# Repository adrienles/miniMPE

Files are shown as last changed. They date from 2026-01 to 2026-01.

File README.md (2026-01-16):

# miniMPE
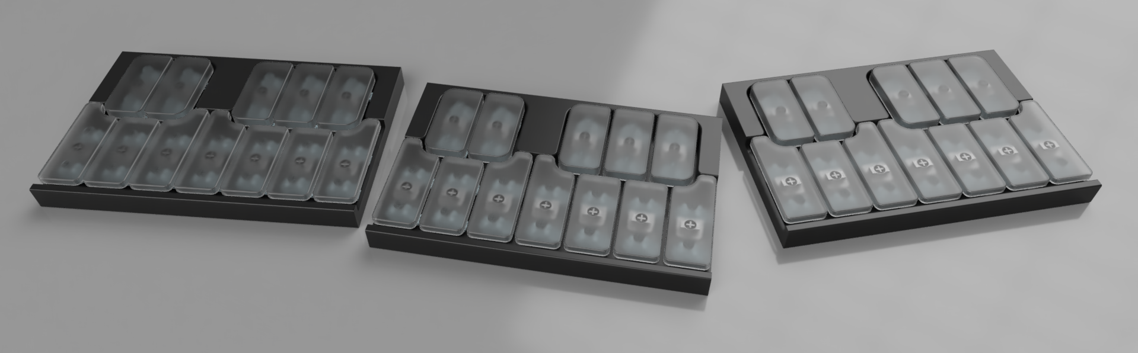
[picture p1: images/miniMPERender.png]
Early prototype render of miniMPE

An ultra-compact expressive octave-sectioned MIDI keyboard
## Idea

Originally inspired by the KORG nanoKeys line of ultra-compact MIDI keyboards, I wanted to design an alternative, with a few improvements:

- Standard key width
- Velocity sensitivity
    - The nanoKeys is not velocity sensitive, as it uses rubber-dome-like keys.
- RGB lighting for scale highlighting and pretty effects
- Daisy-chainable design, to go beyond a 2 octave design
    - This will likely be done using magnetic pogo pin connectors, for an easy and durable connection.
- Open Source :)
## Sub-projects
### MCU Test Board
This is a 4-layer test PCB designed to test one of the chosen MCU picks, alongside its dual USB peripherals, which this project might utilize.
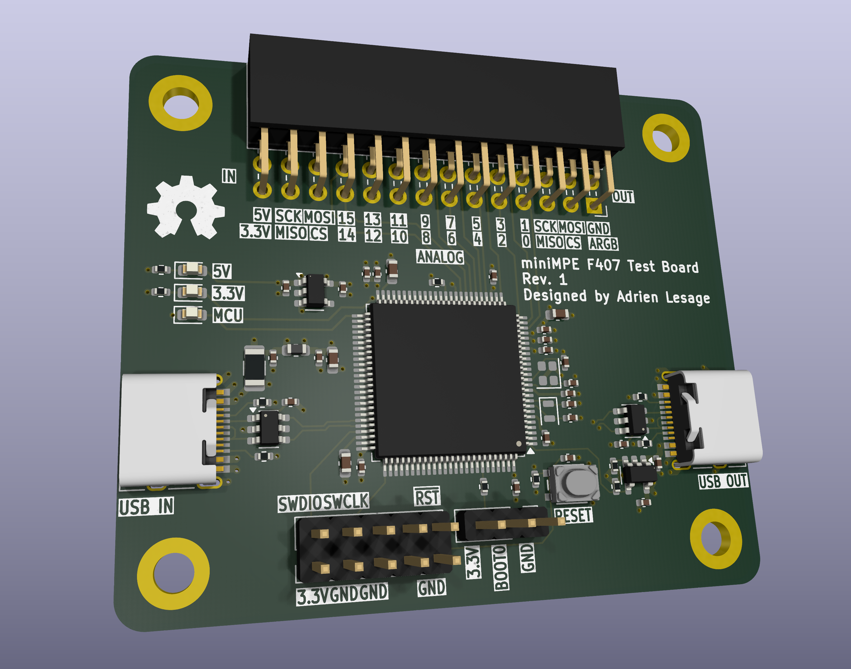
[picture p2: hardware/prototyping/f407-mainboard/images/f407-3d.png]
3D render of F407 PCB

#### Specs
- STM32F407 MCU
    - Dual USB peripherals
- IO header with dual SPI and 16 analog channels
- Dual USB ports
    - Output is protected against over-voltage
- Impedance matched USB and digital signals
- 4-layer design (Signal - Power/Gnd - Gnd - Signal)
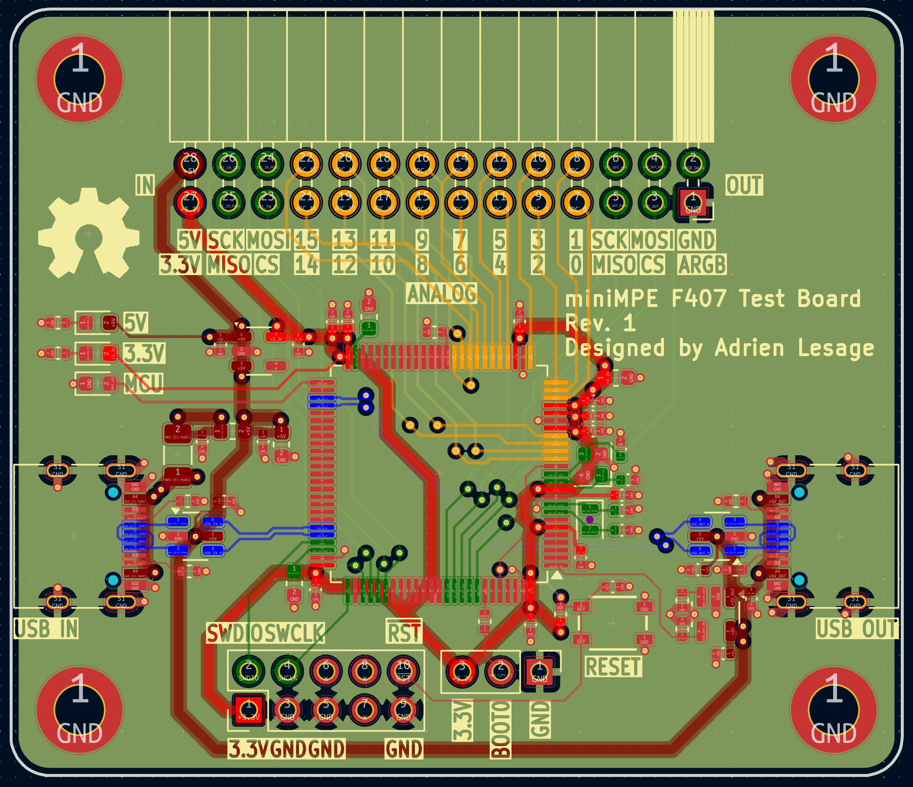
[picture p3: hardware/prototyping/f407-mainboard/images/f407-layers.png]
Layer view of F407 PCB


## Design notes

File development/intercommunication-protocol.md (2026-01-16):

# intercommunication protocol ideas
## options
### usb
#### pros
- naturally, a usb-c connector could be used
- sections could be used and connected to a host device independently, which is a neat feature
#### cons
- to respect the spec (which should be done), only 5v could be passed, requiring each section to regulate its own power instead of simply the host section
- thick protocol layer that is kinda useless in this scenario, could add latency
### i3c
#### pros (especially over i2c)
- hot-join support!
- dynamic addresses (important!)
#### cons
- veeeeery few mcu support it, so it's a no go
### uart
#### pros
- very simple
- could just fifo into the previous section, until the host section
- a very basic mcu could be used
#### cons
- janky i guess?
## choice
- i really like the appeal of each half working on its own, so usb is a natural first choice
  - more extensive testing is needed. if usb does the trick, i'll probably go forward with it

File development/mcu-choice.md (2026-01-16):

# mcu choice
## picks
### stm32f407
#### pros
- powerful
- 2 usb phys
- st, so good software support/docs
#### cons
- expensive
  - ~$2.70/u
- power consumption
  - ~87 mA at max freq + peripherals
    - too much for final product if daisy chaining a bunch (say 5 sections + 1 host for 61 keys, 6*87 = 522 mA, which might be pushing it for bus/battery power)
### ch32v203
#### pros
- decent power
- 2 usb phys
- cheap*
  - c8 @ ~$0.84/u
    - this variant only has 10 adc channels, which would require an extra analog mux
  - rb @ ~$1.69/u
    - this variant has 16 adc channels, which is just enough. however, the cost difference is large enough where the extra mux might be worth it
- low power
  - ~11.8 mA at max freq + peripherals
#### cons
- far from the best support/docs...
- cheap variant has few adc pins

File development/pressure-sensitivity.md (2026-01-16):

# pressure sensitivity
## general idea
- pcb button pad with velostat or other pressure-resistive sheet material
## criteria
- repeatability
- pressure/resistance
- reliability/noise
## ressources
TODO
## iterating
TODO

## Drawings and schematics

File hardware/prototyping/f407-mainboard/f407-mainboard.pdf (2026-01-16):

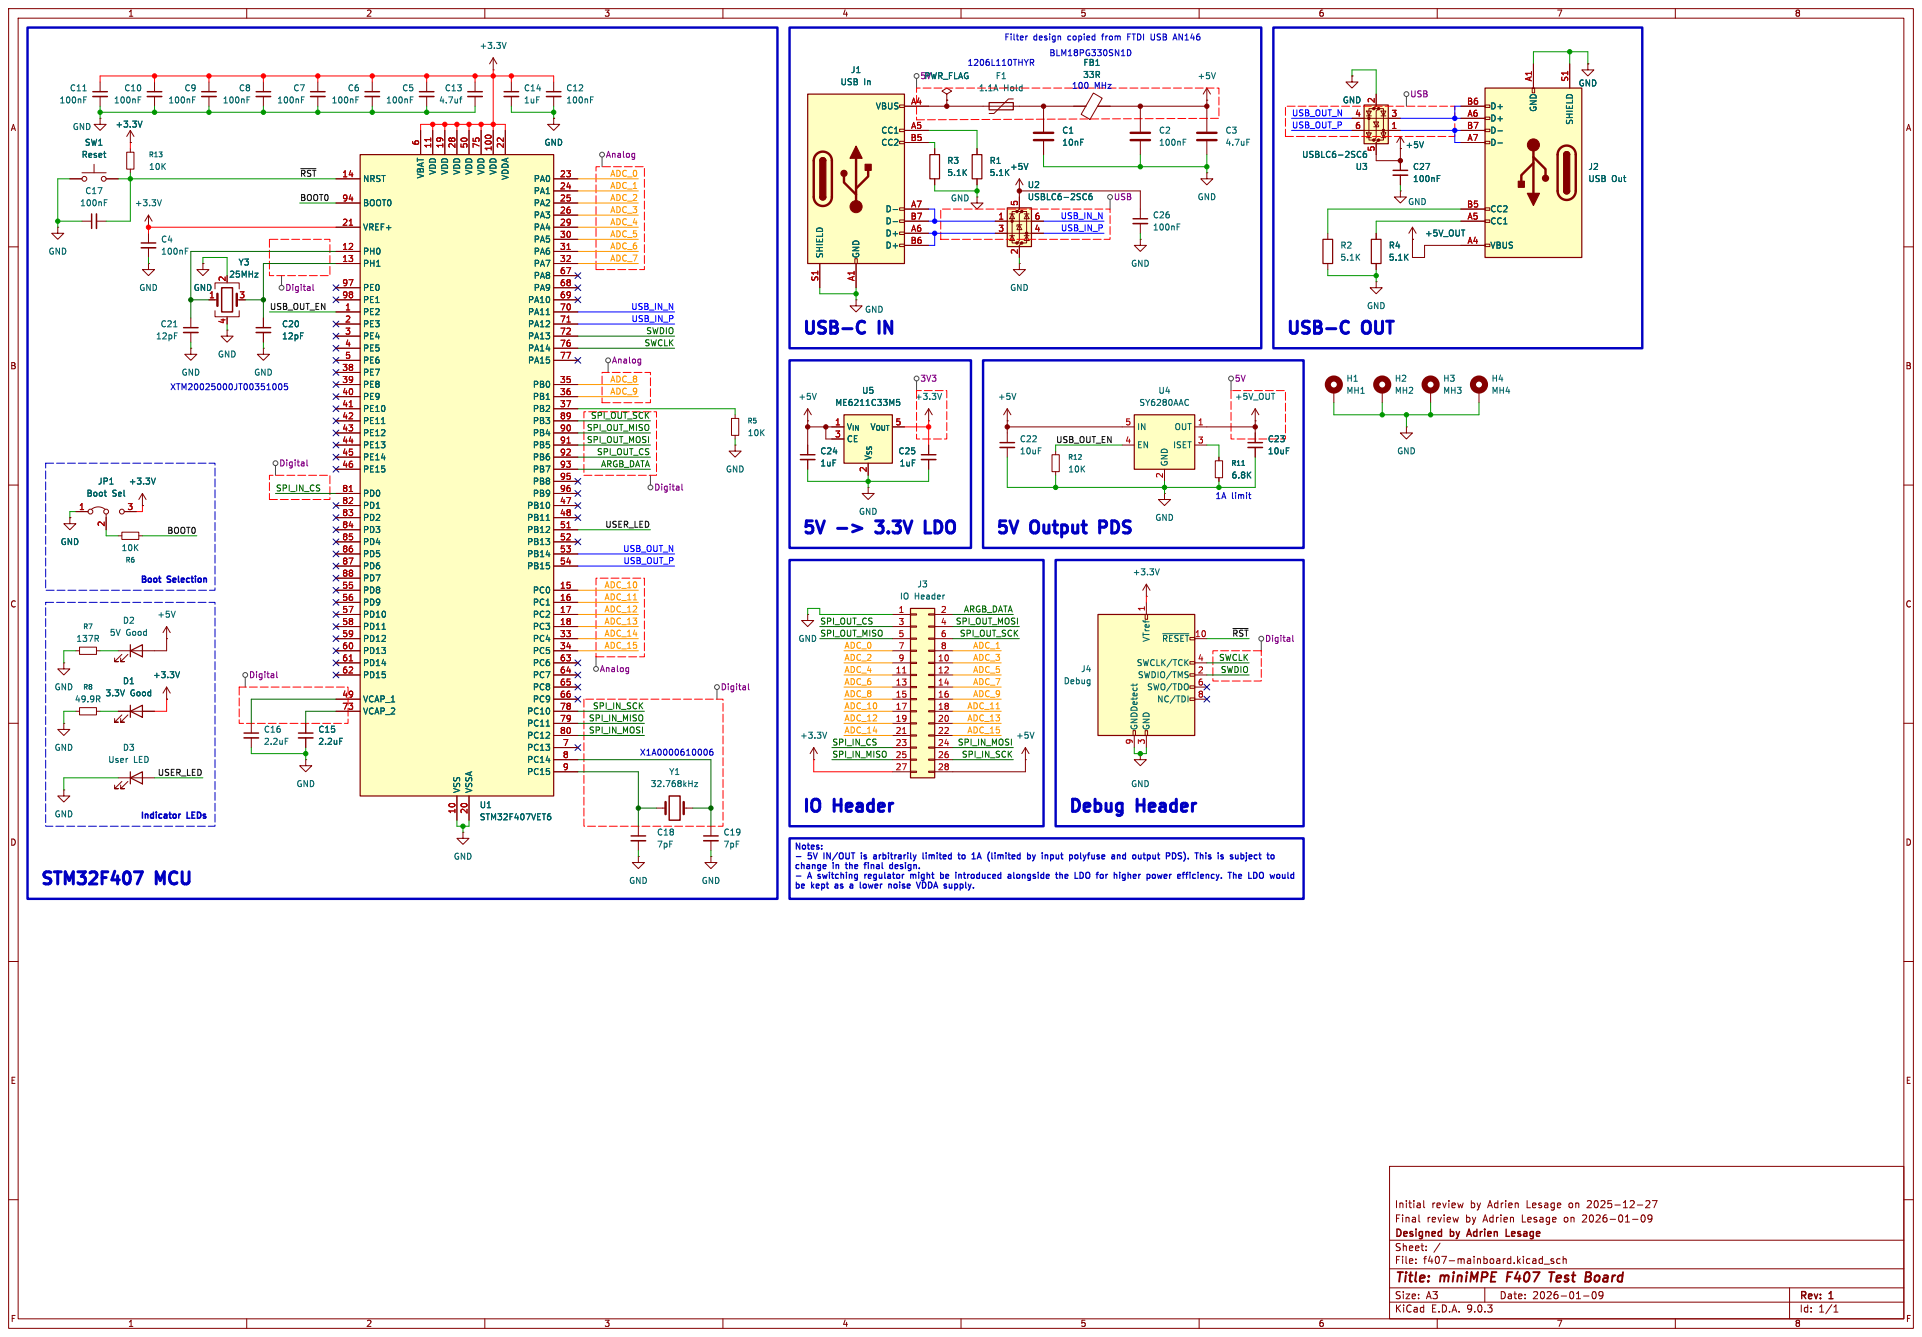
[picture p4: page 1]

6 VDD 11 VDD 19 VDD 28 VSS 10 VDD 50 VSSA 20 VDD 75 VDD 100 VDDA 22 PA0 23 PA1 24 PA2 25 PA3 26 PA4 29 PA5 30 PA6 31 PA7 32 PA8 67 PA9 68 PA10 69 PA11 70 PA12 71 PA13 72 PA14 76 PA15 77 PB0 35 PB1 36 PB2 37 PB3 89 PB4 90 PB5 91 PB6 92 PB7 93 PB8 95 PB9 96 PB10 47 PB11 48 PB12 51 PB13 52 PB14 53 PB15 54 PC0 15 PC1 16 PC2 17 PC3 18 PC4 33 PC5 34 PC6 63 PC7 64 PC8 65 PC9 66 PC10 78 PC11 79 PC12 80 PC13 7 PC14 8 PC15 9 U1STM32F407VET6

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

3 ~{RESET}10 SWCLK/TCK 4 SWDIO/TMS 2 SWO/TDO 6 NC/TDI 8

be kept as a lower noise VDDA supply.

Id: 1/1 Title: miniMPE F407 Test Board

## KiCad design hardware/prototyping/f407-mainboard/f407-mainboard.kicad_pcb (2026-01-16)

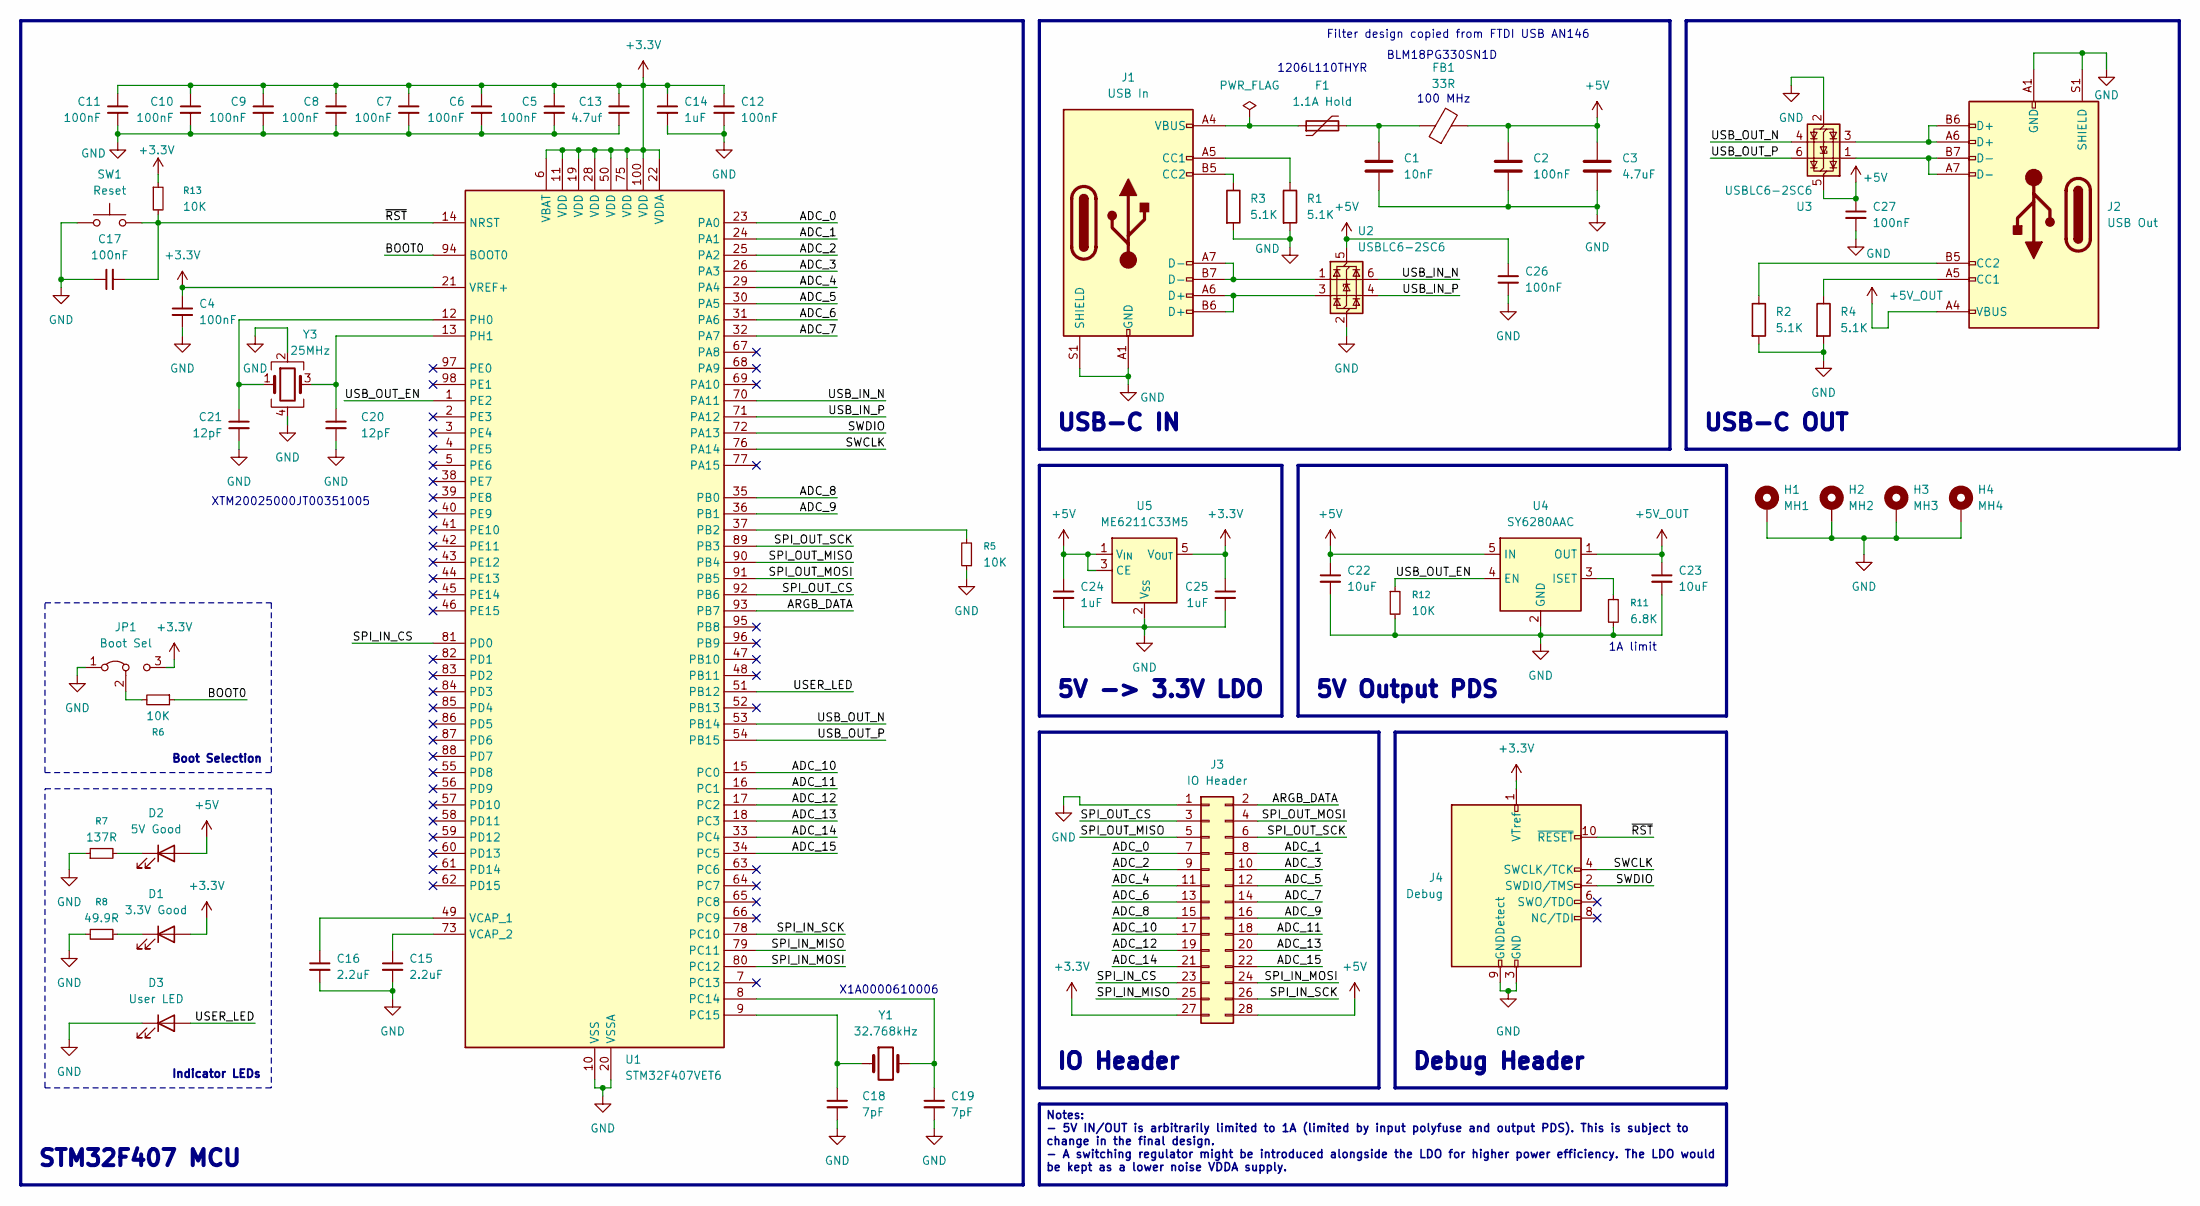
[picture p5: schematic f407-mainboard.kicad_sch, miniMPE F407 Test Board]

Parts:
C1: 10nF; C_0402_1005Metric
C2, C4, C5, C6, C7, C8, C9, C10, C11, C12, C17: 100nF; C_0402_1005Metric; LCSC C1525
C3: 4.7uF; C_0603_1608Metric
C13: 4.7uf; C_0402_1005Metric
C14: 1uF; C_0603_1608Metric
C15, C16: 2.2uF; C_0603_1608Metric
C18, C19: 7pF; C_0402_1005Metric
C20, C21: 12pF; C_0402_1005Metric
C22, C23: 10uF; C_0402_1005Metric
C24, C25: 1uF; C_0402_1005Metric
C26, C27: 100nF; C_0402_1005Metric
D1: 3.3V Good; LED_0603_1608Metric
D2: 5V Good; LED_0603_1608Metric
D3: User LED; LED_0603_1608Metric
F1: 1.1A Hold; Fuse_1206_3216Metric
FB1: 33R; L_0603_1608Metric
H1: MH1; MountingHole_3.2mm_M3_DIN965_Pad
H2: MH2; MountingHole_3.2mm_M3_DIN965_Pad
H3: MH3; MountingHole_3.2mm_M3_DIN965_Pad
H4: MH4; MountingHole_3.2mm_M3_DIN965_Pad
J1: USB In; USB_C_Receptacle_HRO_TYPE-C-31-M-12
J2: USB Out; USB_C_Receptacle_HRO_TYPE-C-31-M-12
J3: IO Header; PinSocket_2x14_P2.54mm_Horizontal
J4: Debug; PinHeader_2x05_P2.54mm_Vertical
JP1: Boot Sel; PinHeader_1x03_P2.54mm_Vertical
R1, R2, R3, R4: 5.1K; R_0402_1005Metric
R5, R6, R12, R13: 10K; R_0402_1005Metric
R7: 137R; R_0402_1005Metric
R8: 49.9R; R_0402_1005Metric
R11: 6.8K; R_0402_1005Metric
SW1: Reset; SW_SKRPACE010_AAL
U1: STM32F407VET6; LQFP-100_14x14mm_P0.5mm; LCSC C28730
U2, U3: USBLC6-2SC6; SOT-23-6; LCSC C7519
U4: SY6280AAC; SOT-23-5; LCSC C55136
U5: ME6211C33M5; SOT-23-5
Y1: 32.768kHz; Crystal_SMD_2012-2Pin_2.0x1.2mm
Y3: 25MHz; Crystal_SMD_2016-4Pin_2.0x1.6mm

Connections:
+3.3V: C4.1, C5.1, C6.1, C7.1, C8.1, C9.1, C10.1, C11.1, C12.1, C13.1, C14.1, C25.1, D1.2 (A), J3.27, J4.1 (VTref), JP1.3 (B), R13.1, U1.6 (VBAT), U1.11 (VDD), U1.19 (VDD), U1.21 (VREF+), U1.22 (VDDA), U1.28 (VDD), U1.50 (VDD), U1.75 (VDD), U1.100 (VDD), U5.5 (V_{OUT})
+5V: C2.1, C3.1, C22.1, C24.1, C26.1, C27.1, D2.2 (A), FB1.2, J3.28, U2.5 (VBUS), U3.5 (VBUS), U4.5 (IN), U5.1 (V_{IN}), U5.3 (CE)
+5V_OUT: C23.1, J2.A4 (VBUS), J2.A9 (VBUS), J2.B4 (VBUS), J2.B9 (VBUS), U4.1 (OUT)
/ADC_0: J3.7, U1.23 (PA0)
/ADC_1: J3.8, U1.24 (PA1)
/ADC_2: J3.9, U1.25 (PA2)
/ADC_3: J3.10, U1.26 (PA3)
/ADC_4: J3.11, U1.29 (PA4)
/ADC_5: J3.12, U1.30 (PA5)
/ADC_6: J3.13, U1.31 (PA6)
/ADC_7: J3.14, U1.32 (PA7)
/ADC_8: J3.15, U1.35 (PB0)
/ADC_9: J3.16, U1.36 (PB1)
/ADC_10: J3.17, U1.15 (PC0)
/ADC_11: J3.18, U1.16 (PC1)
/ADC_12: J3.19, U1.17 (PC2)
/ADC_13: J3.20, U1.18 (PC3)
/ADC_14: J3.21, U1.33 (PC4)
/ADC_15: J3.22, U1.34 (PC5)
/ARGB_DATA: J3.2, U1.93 (PB7)
/BOOT0: R6.1, U1.94 (BOOT0)
/SPI_IN_CS: J3.23, U1.81 (PD0)
/SPI_IN_MISO: J3.25, U1.79 (PC11)
/SPI_IN_MOSI: J3.24, U1.80 (PC12)
/SPI_IN_SCK: J3.26, U1.78 (PC10)
/SPI_OUT_CS: J3.3, U1.92 (PB6)
/SPI_OUT_MISO: J3.5, U1.90 (PB4)
/SPI_OUT_MOSI: J3.4, U1.91 (PB5)
/SPI_OUT_SCK: J3.6, U1.89 (PB3)
/SWCLK: J4.4 (SWCLK/TCK), U1.76 (PA14)
/SWDIO: J4.2 (SWDIO/TMS), U1.72 (PA13)
/USB_IN_N: U1.70 (PA11), U2.6 (I/O1)
/USB_IN_P: U1.71 (PA12), U2.4 (I/O2)
/USB_OUT_EN: R12.1, U1.1 (PE2), U4.4 (EN)
/USB_OUT_N: U1.53 (PB14), U3.4 (I/O2)
/USB_OUT_P: U1.54 (PB15), U3.6 (I/O1)
/USER_LED: D3.2 (A), U1.51 (PB12)
/~RST: C17.2, J4.10 (~RESET), R13.2, SW1.2, U1.14 (NRST)
GND: C1.2, C2.2, C3.2, C4.2, C5.2, C6.2, C7.2, C8.2, C9.2, C10.2, C11.2, C12.2, C13.2, C14.2, C15.2, C16.2, C17.1, C18.2, C19.2, C20.2, C21.2, C22.2, C23.2, C24.2, C25.2, C26.2, C27.2, D3.1 (K), H1.1, H2.1, H3.1, H4.1, J1.A1 (GND), J1.A12 (GND), J1.B1 (GND), J1.B12 (GND), J1.S1 (SHIELD), J2.A1 (GND), J2.A12 (GND), J2.B1 (GND), J2.B12 (GND), J2.S1 (SHIELD), J3.1, J4.3 (GND), J4.5 (GND), J4.9 (GNDDetect), JP1.1 (A), R1.2, R2.2, R3.2, R4.2, R5.1, R7.1, R8.2, R11.2, R12.2, SW1.1, U1.10 (VSS), U1.20 (VSSA), U1.27 (VSS), U1.74 (VSS), U1.99 (VSS), U2.2 (GND), U3.2 (GND), U4.2 (GND), U5.2 (V_{SS}), Y3.2, Y3.4
unnamed: C1.1, F1.2, FB1.1
unnamed: D1.1 (K), R8.1
unnamed: D2.1 (K), R7.2
unnamed: F1.1, J1.A4 (VBUS), J1.A9 (VBUS), J1.B4 (VBUS), J1.B9 (VBUS)
unnamed: J1.A5 (CC1), R1.1
unnamed: J1.B5 (CC2), R3.1
unnamed: J1.A6 (D+), J1.B6 (D+), U2.3 (I/O2)
unnamed: J1.A7 (D-), J1.B7 (D-), U2.1 (I/O1)
unnamed: J2.A5 (CC1), R4.1
unnamed: J2.B5 (CC2), R2.1
unnamed: J2.A6 (D+), J2.B6 (D+), U3.3 (I/O2)
unnamed: J2.A7 (D-), J2.B7 (D-), U3.1 (I/O1)
unnamed: JP1.2 (C), R6.2
unnamed: R5.2, U1.37 (PB2)
unnamed: C19.1, U1.8 (PC14), Y1.2
unnamed: C18.1, U1.9 (PC15), Y1.1
unnamed: C21.1, U1.12 (PH0), Y3.1
unnamed: C20.1, U1.13 (PH1), Y3.3
unnamed: C16.1, U1.49 (VCAP_1)
unnamed: C15.1, U1.73 (VCAP_2)
unnamed: R11.1, U4.3 (ISET)

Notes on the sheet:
USB-C IN
Indicator LEDs
Boot Selection
1206L110THYR
BLM18PG330SN1D
Debug Header
XTM20025000JT00351005
USB-C OUT
STM32F407 MCU
X1A0000610006
Filter design copied from FTDI USB AN146
100 MHz
5V -> 3.3V LDO
IO Header
1A limit
5V Output PDS
Notes: - 5V IN/OUT is arbitrarily limited to 1A (limited by input polyfuse and output PDS). This is subject to change in the final design. - A switching regulator might be introduced alongside the LDO for higher power efficiency. The LDO would be kept as a lower noise VDDA supply.

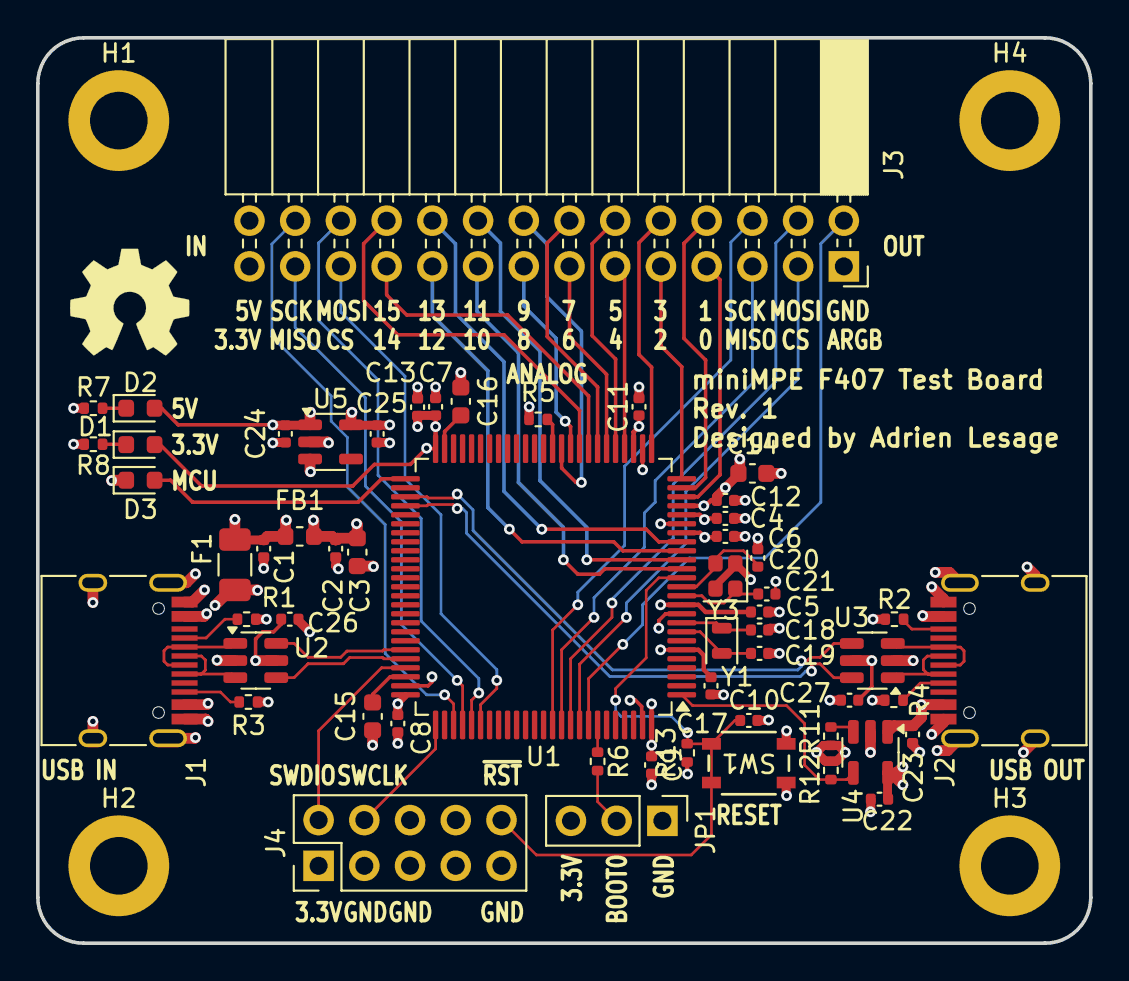
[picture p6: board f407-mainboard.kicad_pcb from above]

Board: 4 copper layers, 58.5 x 50.3 mm, 60 parts (0 on the bottom side), 60 nets.

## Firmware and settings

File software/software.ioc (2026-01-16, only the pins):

Mcu.UserName=STM32F407VETx
PA0-WKUP.Signal=ADCx_IN0
PA1.Signal=ADCx_IN1
PA11.Signal=USB_OTG_FS_DM
PA12.Signal=USB_OTG_FS_DP
PA13.Signal=SYS_JTMS-SWDIO
PA14.Signal=SYS_JTCK-SWCLK
PA2.Signal=ADCx_IN2
PA3.Signal=ADCx_IN3
PA4.Signal=ADCx_IN4
PA5.Signal=ADCx_IN5
PA6.Signal=ADCx_IN6
PA7.Signal=ADCx_IN7
PB0.Signal=ADCx_IN8
PB1.Signal=ADCx_IN9
PB14.Signal=USB_OTG_HS_DM
PB15.Signal=USB_OTG_HS_DP
PB3.Signal=SPI1_SCK
PB4.Signal=SPI1_MISO
PB5.Signal=SPI1_MOSI
PB6.Signal=I2C1_SCL
PB7.Signal=I2C1_SDA
PC0.Signal=ADCx_IN10
PC1.Signal=ADCx_IN11
PC10.Signal=UART4_TX
PC11.Signal=UART4_RX
PC14-OSC32_IN.Signal=RCC_OSC32_IN
PC15-OSC32_OUT.Signal=RCC_OSC32_OUT
PC2.Signal=ADCx_IN12
PC3.Signal=ADCx_IN13
PC4.Signal=ADCx_IN14
PC5.Signal=ADCx_IN15
PD10.Signal=GPIO_Output
PH0-OSC_IN.Signal=RCC_OSC_IN
PH1-OSC_OUT.Signal=RCC_OSC_OUT
